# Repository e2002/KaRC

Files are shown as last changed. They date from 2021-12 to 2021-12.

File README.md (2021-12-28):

# KaRC
Remote control of the [KaRadio](https://github.com/karawin/Ka-Radio32) via telnet.  
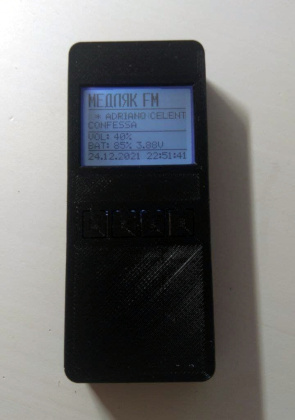
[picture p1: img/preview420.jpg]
Preview
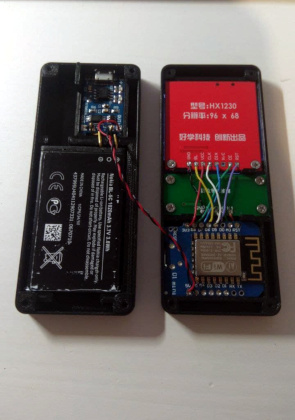
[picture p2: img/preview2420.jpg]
Preview
 
## Dependencies
- AutoConnect Library https://github.com/Hieromon/AutoConnect
- HX1230_FB Library https://github.com/cbm80amiga/HX1230_FB
- OneButton Library https://github.com/mathertel/OneButton
## BOM
- HX1230 Display http://chip69.ru/catalog/108689
- Wemos D1 Mini https://aliexpress.ru/item/32651747570.html
- 1x4 buttons 5 pins board https://aliexpress.ru/item/32886402552.html
- TC4056 module https://aliexpress.ru/item/32825983420.html
- BL5C battery https://aliexpress.ru/item/1005002239609662.html
- Screws https://aliexpress.ru/item/1005001870799002.html
- Paper clips brass plated https://www.erichkrause.com/en/catalog/Paper_clips_105/paper_clips_brass_plated_erichkrause_28mm_plastic_box_200_pcs_19739/
## Assembly 
### Wemos
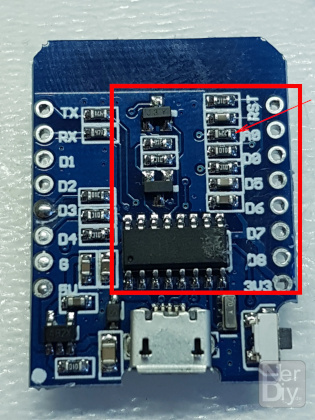
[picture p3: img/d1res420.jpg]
D1
  
Replace the 220kOhm resistor on the circuit board of the Wemos D1 Mini with a 510kOhm resistor.  
Connect pin A0 to pin 5v.
### Display
| HX1230 | Wemos |
| --- | --- |
| RST | D3 |
| CS  | D8 |
| DIN | D7 |
| CLK | D5 |
| VCC | VCC |
| BL | D6 |
| GND | GND |
### Buttons
| 1x4 Module | Wemos |
| --- | --- |
| K1 | D4 |
| K2 | D2 |
| K3 | D1 |
| K4 | RST |
| GND | GND |
### TC4056 module
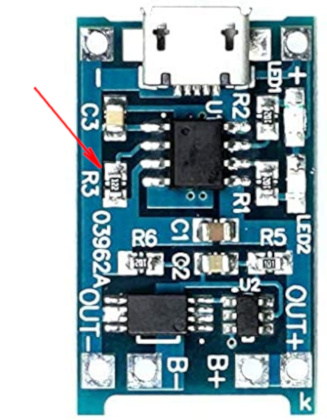
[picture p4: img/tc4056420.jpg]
TC4056
  
Replace the 1.2kOhm resistor on the TC4056 module with a 3kOhm resistor.  
| TC4056 | BL5C/Wemos |
| --- | --- |
| B- | Batt- |
| B+ | Batt+ |
| OUT- | GND |
| OUT+ | 5V |
## Initial setup
#### _In progress_
## Control
|  | BTN1 | BTN2 | BTN3 | BTN4 |
| --- | --- | --- | --- | --- |
| Click | Vol- | Play/Pause | Vol+ | Reset |
| DblClick | - | Show IP | - | - |
| LongPress | Deep Sleep | Play List | Show IP | - |
## Known issues
#### Slowly connects to KaRadio when playback is stopped.  
Solution: -  
#### Does not turn on when the battery is connected.  
Solution: briefly apply power to the module.

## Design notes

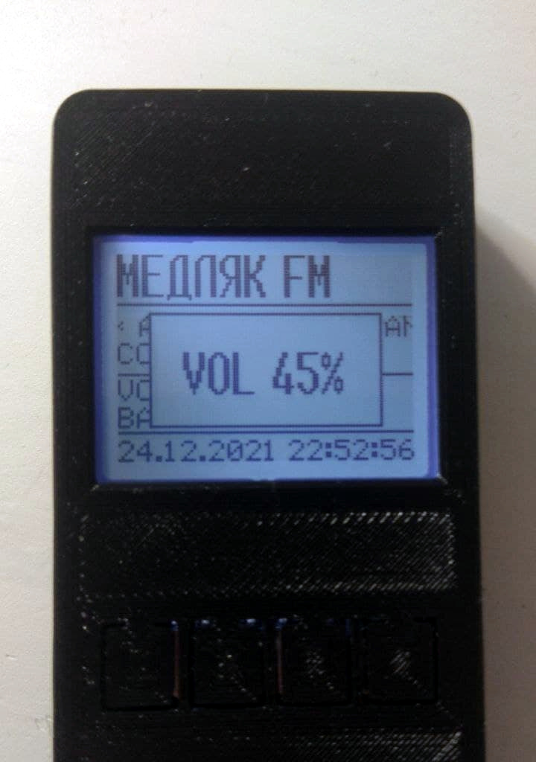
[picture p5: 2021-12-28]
img/preview7.jpg

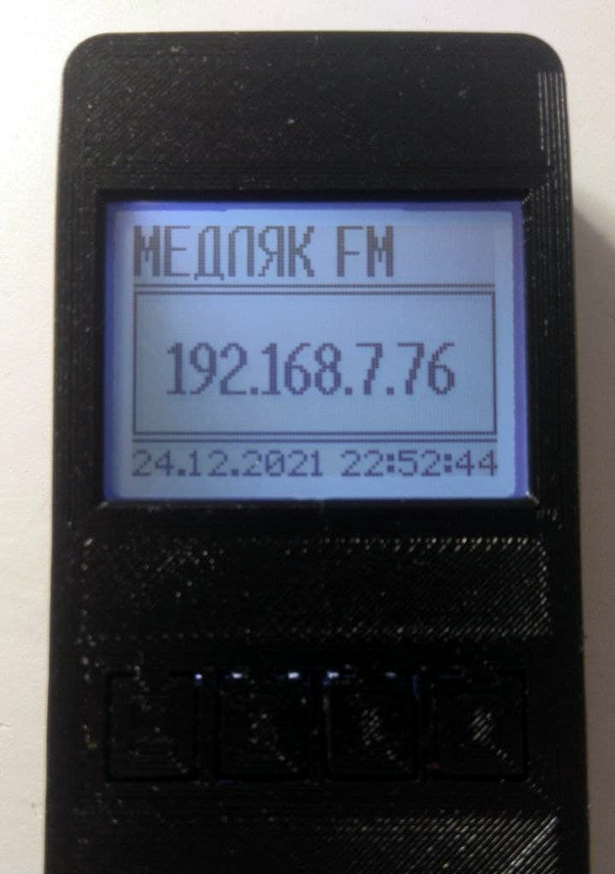
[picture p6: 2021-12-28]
img/preview6.jpg

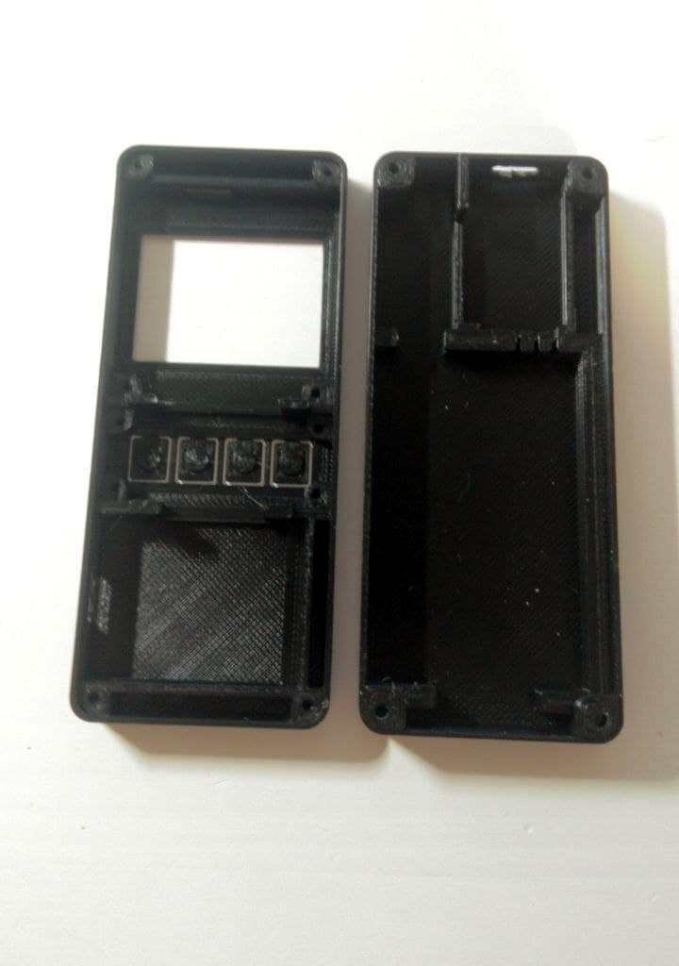
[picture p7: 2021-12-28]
img/preview4.jpg

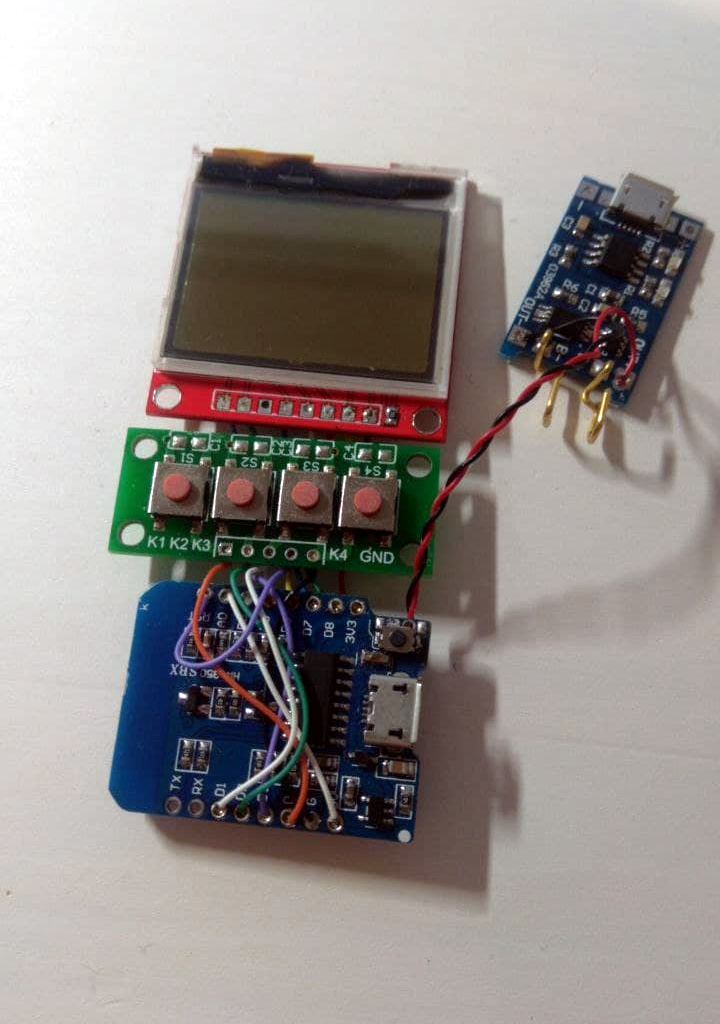
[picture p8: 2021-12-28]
img/preview3.jpg

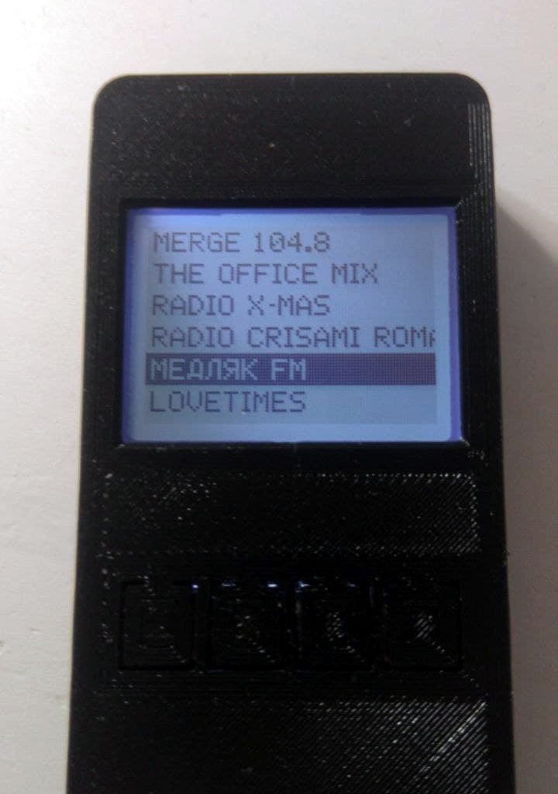
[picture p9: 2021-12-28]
img/preview5.jpg

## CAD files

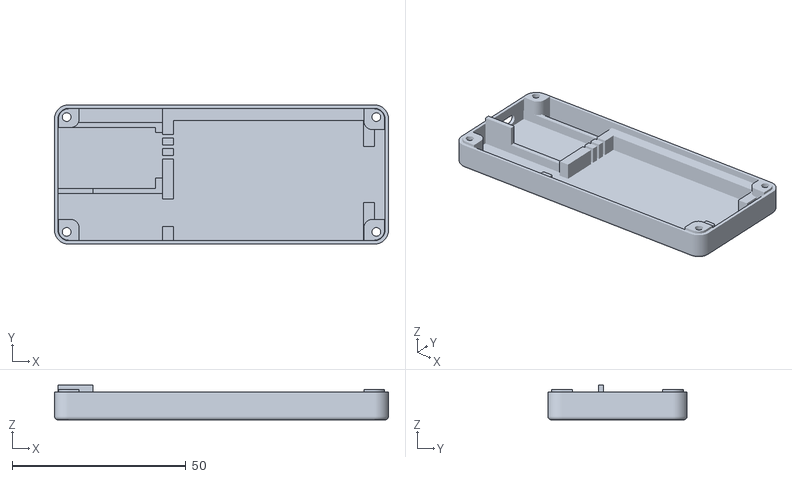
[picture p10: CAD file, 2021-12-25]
case_stl/back.stl
96.0 x 40.0 x 10.0

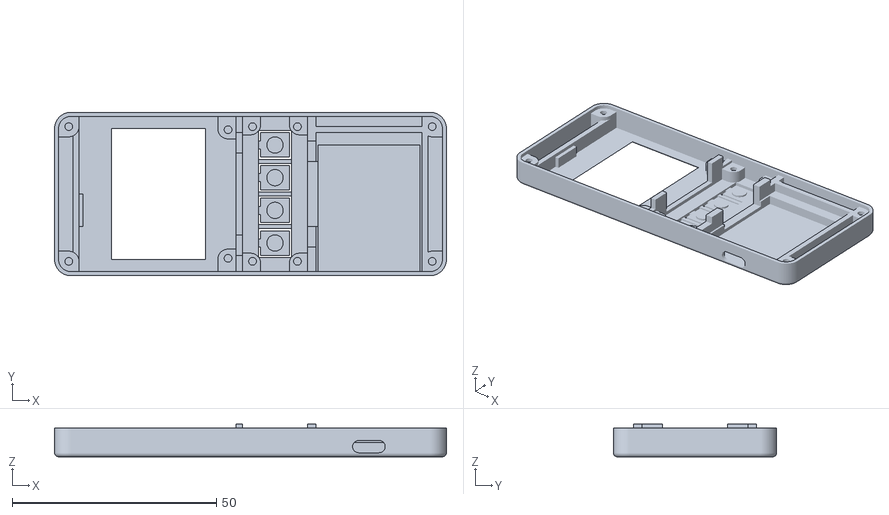
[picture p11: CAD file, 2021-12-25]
case_stl/front.stl
96.0 x 40.0 x 8.00

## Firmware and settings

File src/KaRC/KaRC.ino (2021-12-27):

#include "dbg.h"
#include "HXScreen.h"

HXScreen screen;

#include "timers.h"
#include "parser.h"
#include "network.h"
#include "buttons.h"

void setup() {
  dbgbegin(115200);
  setupButtons();
  screen.init();
  screen.drawSplash("connecting");
  connectToCli();
}

void loop() {
  buttonTicks();
  handleCli();
}

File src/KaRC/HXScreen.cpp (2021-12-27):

#include "HXScreen.h"
#include "HX1230_FB_EX.h"
#include "term9x14_font.h"
#include "small4x6_font.h"

HX1230_FB_EX lcd(LCD_RST, LCD_CS);

struct plItem
{
  byte idx;
  char name[40];
};
plItem playList[255];


HXScreen::HXScreen() {
  screenMode = SCREENBOOT;
  playlistSize = 0;
  timestamp = 0;
}

void HXScreen::init() {
  lcd.init();
  lcd.cls();
  lcd.display();
  pinMode(LCD_BL, OUTPUT);
  digitalWrite(LCD_BL, HIGH);
  pinMode(VINPUT, INPUT);
  lcd.setFont(Small4x6PL);
  slNameset.init(&lcd, 0, HX1230RUS, 7);
  slTitle.init(&lcd, 20, MedvedFont1230, 5);
  slSong.init(&lcd, 29, MedvedFont1230, 5);
  timeTicks.attach_ms(1000, [this]() {
    this->clockTick();
  });
  battTick();
  battTicks.attach_ms(20000, [this]() {
    this->battTick();
  });
}

void HXScreen::setName(const char* txt) {
  slNameset.setText(txt);
}

void HXScreen::setTitle(const char* txt) {
  slTitle.setText(txt);
}

void HXScreen::setSong(const char* txt) {
  slSong.setText(txt);
}

void HXScreen::setTime(time_t ts) {
  isTimeSet = true;
  timestamp = ts;
}

void HXScreen::setVolLevel(int vol) {
  volInt = vol;
  sprintf(volLevel, "VOL: %d%%", vol);
}

int HXScreen::getVolLevel() {
  return volInt;
}

void HXScreen::drawClock() {
  if (isTimeSet) {
    struct tm *dt;
    char strdate[40];
    char strclock[40];
    int dM, dH;
    dt = gmtime(&timestamp);
    dH = dt->tm_hour - dt->tm_hour % 10 == 10 ? 4 : 0;
    dM = dt->tm_min - dt->tm_min % 10 == 10 ? 4 : 0;
    sprintf(strdate, "%02d.%02d.%04d", dt->tm_mday, (dt->tm_mon) + 1, dt->tm_year + 1900);
    sprintf(strclock, "%02d:%02d:%02d", dt->tm_hour, dt->tm_min, dt->tm_sec);
    int clcw = lcd.strWidth(strclock);
    lcd.setFont(MedvedFont1230);
    lcd.printStr(0, 61, strdate);
    lcd.printStr(97 - clcw, 61, strclock);
  }
}

void HXScreen::setScreen(byte sm) {
  if (screenMode == 0) bootClear();
  screenMode = sm;
}

void HXScreen::drawBoot() {
  lcd.cls();
  for (byte i = 0; i < BOOTSIZE; i++) {
    if (strlen(bootArray[i]) == 0) {
      lcd.display();
      return;
      break;
    }
    lcd.printStr(0, i * 8, bootArray[i]);
  }
  lcd.display();

}

void HXScreen::drawPlayList() {
  lcd.cls();
  lcd.setFont(MedvedFont1230);
  int row = 2;
  int delta = startNamesetNum - 4;
  if (delta < 0) delta = 0;
  if (delta > playlistSize - PLSIZE) delta = playlistSize - PLSIZE;
  for (byte i = 0; i < PLSIZE; i++) {
    if (strlen(playList[i + delta].name) == 0) {
      lcd.display();
      return;
      break;
    }
    lcd.printStr(2, row, playList[i + delta].name);
    if (i + delta == startNamesetNum) lcd.fillRect(0, row - 2, 96, 11, 2);
    row += 11;
  }
  lcd.display();
}

void HXScreen::showDialog(const char* s, unsigned int tout) {
  strcpy(dialog, s);
  dialogTimeout = tout;
  isDrawDialog = true;
}

void HXScreen::drawDialog() {
  if (isDrawDialog) {
    lcd.setFont(HX1230RUS);
    int w = lcd.strWidth(dialog);
    lcd.fillRect(0, 18, 96, 39, 0);
    lcd.drawRect(0, 18, 96, 39, 1);
    lcd.printStr((96 - w) / 2, 32, dialog);
  }
}

void HXScreen::drawVolumeDialog() {
  if (isDrawVolume) {
    lcd.setFont(HX1230RUS);
    char v[12];
    sprintf(v, "VOL %d%%", volInt);
    int w = lcd.strWidth(v);
    lcd.fillRect(10, 19, 76, 38, 0);
    lcd.drawRect(10, 19, 76, 38, 1);
    lcd.printStr((96 - w) / 2, 32, v);
  }
}

void HXScreen::drawPlayer() {
  slNameset.ticks();
  lcd.drawLineH(0, 96, 16, 1);
  slTitle.ticks();
  slSong.ticks();
  lcd.drawLineH(0, 96, 39, 1);
  lcd.printStr(0, 41, volLevel);
  lcd.printStr(0, 50, battLevel);
  lcd.drawLineH(0, 96, 58, 1);
  drawClock();
  drawVolumeDialog();
  drawDialog();
}

byte HXScreen::bootPush(const char* s) {
  for (byte i = 0; i < BOOTSIZE; i++) {
    if (strlen(bootArray[i]) == 0) {
      strcpy(bootArray[i], s);
      drawBoot();
      return i;
      break;
    }
  }
  for (byte i = 0; i < BOOTSIZE - 1; i++) {
    strcpy(bootArray[i], bootArray[i + 1]);
  }
  strcpy(bootArray[BOOTSIZE - 1], s);
  drawBoot();
  return BOOTSIZE - 1;
}

void HXScreen::bootCat(byte pos, const char* s) {
  strcat(bootArray[pos], s);
  drawBoot();
}

void HXScreen::plPush(byte ind, char* s) {
  strncpy(playList[playlistSize].name, s, 40);
  playList[playlistSize].idx = ind;
}

void HXScreen::drawSplash( char* s) {
  lcd.cls();
  //lcd.drawBitmap(logo, -2, 8 , 84, 48);
  lcd.drawBitmap(logo2bw, -2, 0 , 60, 60);
  lcd.setFont(MedvedFont1230);
  int strw = lcd.strWidth(s);
  lcd.printStr(48 - strw / 2, 58, s);
  lcd.display();
}

void HXScreen::stepMode() {
  if (screenMode == SCREENBOOT) return;
  screenMode++;
  if (screenMode == SCREENLIST) {
    for (int i = 0; i < playlistSize; i++) {
      if (playList[i].idx == nsNum) {
        startNamesetNum = i;
        break;
      }
    }
  }
  if (screenMode > SCREENLIST) screenMode = SCREENPLAY;
}

void HXScreen::nextItem() {
  startNamesetNum++;
  if (startNamesetNum > playlistSize - 1) startNamesetNum = playlistSize - 1;
}

void HXScreen::prevItem() {
  startNamesetNum--;
  if (startNamesetNum < 0) startNamesetNum = 0;
}

int HXScreen::currentItem() {
  return playList[startNamesetNum].idx;
}

void HXScreen::playlistSizePlus() {
  playlistSize++;
}

byte HXScreen::getScreenMode() {
  return screenMode;
}

void HXScreen::powerOff() {
  digitalWrite(LCD_BL, LOW);
  lcd.displayMode(HX1230_POWER_OFF);
  ESP.deepSleep(0);
}

void HXScreen::showVolume() {
  isDrawVolume = true;
}

void HXScreen::hideVolume() {
  isDrawVolume = false;
}

void HXScreen::bootClear() {
  for (byte i = 0; i < BOOTSIZE; i++) {
    strcpy(bootArray[i], "");
  }
}

void HXScreen::clockTick() {
  timestamp++;
  if (dialogTimeout > 0) {
    dialogTimeout--;
  } else {
    isDrawDialog = false;
  }
}

void HXScreen::battTick() {
  long sum = 0;
  float voltage = 0.0;
  const float battery_max = 4.04;
  const float battery_min = 2.95;
  char vfloatStr[10];
  float voltageValue;
  int voltagePercent;
  for (int i = 0; i < 20; i++)
  {
    sum += analogRead(VINPUT);
    delayMicroseconds(1000);
  }

  voltage = sum / (float)20;
  voltageValue = voltage / 178;
  voltagePercent = map(voltageValue * 100, 295, 404, 0, 100);
  if (voltagePercent > 100)
    voltagePercent = 100;

  dtostrf(voltageValue, 4, 2, vfloatStr);
  sprintf(battLevel, "BAT: %d%% %sV", voltagePercent, vfloatStr);
}

void HXScreen::display() {
  lcd.cls();
  switch (screenMode) {
    case SCREENBOOT: {
        //drawBoot();
        break;
      }
    case SCREENPLAY: {
        drawPlayer();
        break;
      }
    case SCREENLIST: {
        drawPlayList();
        break;
      }
  }
  lcd.display();
}
